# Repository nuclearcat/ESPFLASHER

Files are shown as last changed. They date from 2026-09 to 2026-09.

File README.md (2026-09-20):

# ESPFLASHER
Inexpensive ESP32/ESP8266 programmer

This device implements a USB programmer for ESP32/ESP8266 devices with traditional programming pin management (EN/BOOT0) using [RTS DTR bridge][1].

It also differs from traditional USB-UART converters by a powerful LDO, which allows you to easily power the ESP32 / ESP8266 and related peripherals.
Earlier revisions were manufactured by JLCPCB and tested for programming various devices.

**V3 has not been tested on physical hardware (IRL) yet.** It uses [USB-C with USB 2.0 data](docs/usb-c.md), corrects the header labels and board-edge clearance, uses a ceramic-compatible TI regulator, and retains a single power LED beside the programming header. The RX/TX activity LEDs and their drivers have been removed. It has passed the KiCad checks described in [the revision notes](docs/revision-3.md). Gerbers, BOM and CPL are included.

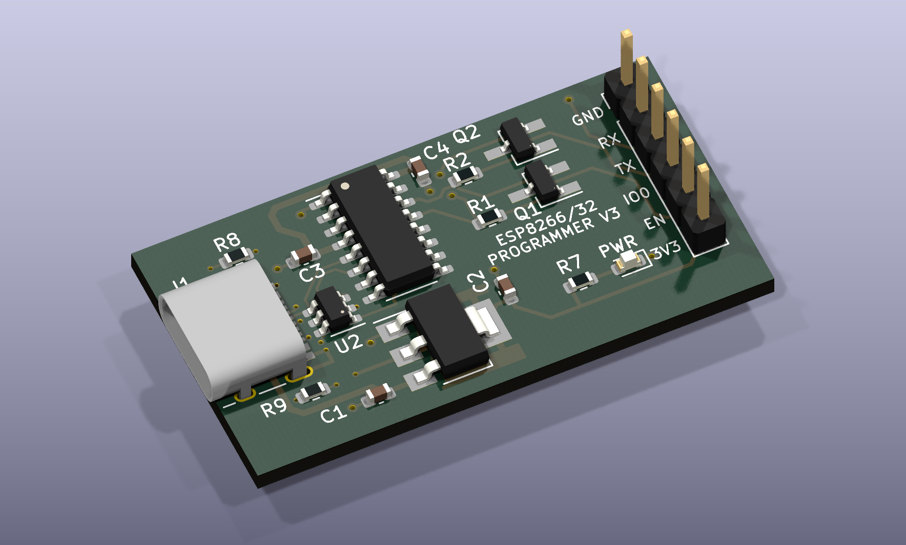
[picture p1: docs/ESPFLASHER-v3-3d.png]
ESPFLASHER V3 3D preview with USB-C connector


[1]: https://raw.githubusercontent.com/nodemcu/nodemcu-devkit/master/Documents/NODEMCU_DEVKIT_SCH.png "Also called Node-MCU auto-program circuit"

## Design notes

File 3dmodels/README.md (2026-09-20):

# USB-C connector model

`HRO_TYPE-C-31-M-12.step` is the HRO TYPE-C-31-M-12 model from
[Keebio-Parts.pretty](https://github.com/keebio/Keebio-Parts.pretty/blob/1486bef23f020c31bf69123c93da199850cc7243/3dmodels/HRO%20%20TYPE-C-31-M-12.step),
copied without modifying its contents. The STEP header credits `ryotagoto`.
The upstream repository's MIT license is included in `LICENSE.keebio`.

J1 references `${KIPRJMOD}/3dmodels/HRO_TYPE-C-31-M-12.step`, so the model
travels with the project and does not require a system library installation.
KiCad model settings:

| Setting | X | Y | Z |
| --- | ---: | ---: | ---: |
| Scale | 1 | 1 | 1 |
| Rotation (degrees) | -90 | 0 | 0 |
| Offset (mm) | -4.47 | -3.65 | 0 |

The rotation and Y/Z offsets follow the upstream assembly footprint, which
uses the same shell mounting-hole coordinates as J1. The X offset centers the
model's 8.94 mm width precisely (upstream uses -4.45 mm). Its shell leg centers
then match the footprint's X = ±4.32 mm mounting slots. The body rests at the
PCB top surface and its opening faces the left board edge. Placement was
checked in KiCad top and oblique renders; the model is for visualization,
with the manufacturer drawing remaining the assembly reference.

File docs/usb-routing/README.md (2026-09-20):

# USB routing comparison

These are historical views of the Micro-USB routing change, before the later
removal of the RX/TX indicators, relocation of the power LED, and USB-C conversion. See the
[current board preview](../ESPFLASHER-v3-3d.png) and [revision notes](../revision-3.md)
for the final V3 layout. The [USB-C conversion](../usb-c.md) supersedes the
connector placement and routing shown here.

These images are generated directly from the KiCad PCB. The before views show
the V2 board immediately before this USB routing change, including the earlier
header-label, regulator and board-edge fixes. Before/after views use identical
camera settings or drawing viewports. Back copper is viewed from the top, so its
features line up with the front layer above it.

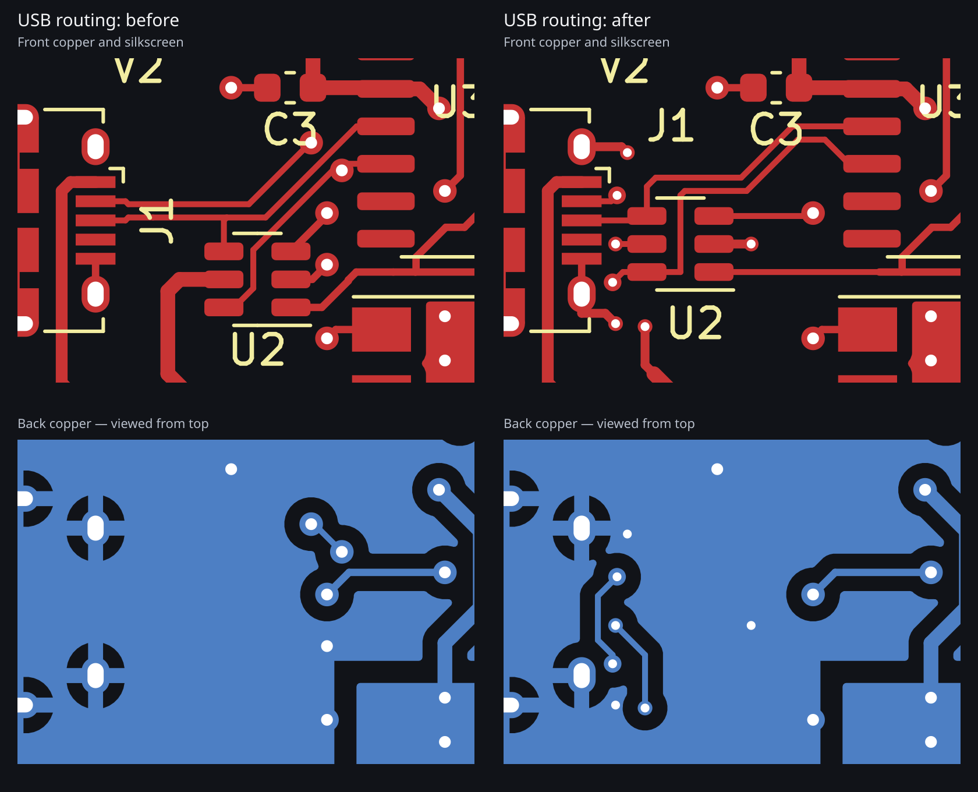
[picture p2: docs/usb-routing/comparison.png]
Before and after USB routing, front and back copper


| View | Before | After |
| --- | --- | --- |
| Full front copper and silkscreen | [Before](before.png) | [After](after.png) |
| Full board 3D render | [Before](before-3d.png) | [After](after-3d.png) |

U2 moves 2.14 mm toward J1 and 1.20 mm upward, with no rotation. Both USB traces
now enter and leave their respective U2 pads rather than connecting protection
through branch traces. The pad assignments and all schematic connections remain
unchanged. The other U2 channels and its supply are rerouted to the new position.

The connector and CH340 have opposite D+/D− pad order. The two-via D− crossover
is now on the connector side of U2, leaving the main protected USB run on the
front layer. That run uses 0.20 mm tracks with 0.25 mm edge-to-edge spacing on
its paired sections, then fans out to the CH340 pads. There are no length-tuning
meanders. Ground vias beside the connector shell connections stitch the layers
near the crossover, and U2 has a short connection to a ground via beside pin 2.

The existing 0.20 mm trace width is retained. This is not a claim of verified
90-ohm differential impedance: that requires a specified fabrication stackup and
an impedance calculation. The back ground fill is continuous under the main
paired route, checked against the filled copper geometry.

KiCad DRC reports no new violations, no unconnected pads and no schematic/PCB
parity issues. The existing J1 footprint-type error and nine footprint-library
warnings remain. Only U2 changes position; all components retain their pin-net
assignments and orientation. Both assembly position files, Gerber archives and
the IPC netlist are updated.

**The current V3 revision remains untested on physical hardware.** USB enumeration, repeated flashing
and ESD performance have not been bench-validated.

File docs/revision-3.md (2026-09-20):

# PCB V3

The earlier Micro-USB board was marked V2. This USB-C revision is V3; its
silkscreen, PCB/schematic revision fields and manufacturing files use revision 3.

This revision addresses review items 1–3, replaces Micro-USB with USB-C,
improves USB routing, and simplifies the LED circuit. The board outline and
header pinout are unchanged. U2 moves to accommodate the larger connector,
and D3/R7 move beside the programming header. The RX/TX indicator branches
are removed. See the [USB-C notes](usb-c.md) for the current connector and
the [USB routing comparison](usb-routing/README.md) for historical Micro-USB views.

## Header labels

Each J2 label is placed at the corresponding pad's Y coordinate, at 2.54 mm pitch.
The power pin is marked `3V3` rather than `VCC`. RX and TX are named from the
programmer's perspective.

| J2 pin | Label | Connection |
| --- | --- | --- |
| 1 (square pad) | GND | Ground |
| 2 | RX | Programmer RX; connect to target TX |
| 3 | TX | Programmer TX; connect to target RX |
| 4 | IO0 | Target boot strap |
| 5 | EN | Target enable/reset |
| 6 | 3V3 | Programmer 3.3 V output |

## Board edge

The project now enforces 0.3 mm copper-to-board-edge clearance. The bottom ground
bridge was moved from Y=60.6 mm to Y=60.4 mm, giving its 0.5 mm tracks 0.35 mm
clearance to the Y=61 mm outline. All zones were refilled with the new rule;
the ground fill is inset approximately 0.3005 mm from the outline.

## Regulator and output capacitor

U1 is **Texas Instruments TLV1117LV33DCYR**, LCSC/JLCPCB **C15578**. Its pinout
matches the existing SOT-223 footprint: pin 1 GND, pin 2 and tab OUT, pin 3 IN.
A project-local symbol records the exact part without relying on an AMS1117
symbol name.

C2 remains the existing 22 µF ceramic capacitor. The
[TI datasheet, section 8.2.2.1](https://www.ti.com/lit/ds/symlink/tlv1117lv.pdf)
specifies ceramic-capacitor stability with zero minimum ESR, recommends at least
1 µF nominal, and requires more than 0.5 µF effective capacitance after bias,
temperature and aging. Preserve that requirement when substituting C2.
Do not substitute an ordinary AMS1117 or TLV1117 for the specified **LV** part.

The replacement is for nominal 5 V USB input: recommended maximum input is 5.5 V
(6 V absolute maximum). This change does not establish a continuous output-current
rating or add reverse-current blocking. Disconnect J2 pin 6 when using an
independently powered target.

## Power indicator

The RX/TX activity LEDs D1/D2, their 2N7002 drivers Q3/Q4, and resistors R3–R6
are removed from the schematic, PCB, BOMs and placement files. Their UART and
supply branch traces are removed as well. The former idle-on LED erratum no
longer applies. Programming and UART connections remain intact.

D3 is the sole remaining LED. It moves to (111.20, 55.62) mm, beside J2's 3V3
label, with a `PWR` silkscreen label. Its 1 kΩ resistor R7 moves to
(107.50, 55.62) mm. Both rotate to 180 degrees; D3's cathode is on the right.
The circuit remains +3V3 → R7 → D3 → GND, so it indicates the presence of the
3.3 V rail rather than UART activity. Existing references are retained for
traceability. The 3.3 V trace to J2 is rerouted below the indicator, and copper
zones are refilled. All other component positions and orientations remain as
they were immediately before this LED change.

## Manufacturing and validation

Both `production/ESPFLASHER.zip` and `jlcpcb/gerber/GERBER-ESPFLASHER.zip` contain
the same regenerated V3 copper, solder mask, paste, silkscreen, outline and drill
files. Both BOMs are regenerated from the current schematic's JLCPCB fields,
including the sourcing updates already present in the schematic before these changes.
The backup archive under `production/backups/` remains historical.

The final USB-C J1 position is (83.18, 50.00) mm at -90 degrees in KiCad,
with U2 at (90.525, 50.80) mm. R8 is at (86.50, 43.50) mm / 0 degrees and
R9 is at (86.50, 56.25) mm / 180 degrees. Both position files include these
changes and the D3/R7 moves; the eight removed indicator components are
omitted. Other existing assembly rotation adjustments are retained. The U1
value in the JLCPCB position file is updated. Confirm J1's mating direction,
pin 1 of U1/U2 and D3's cathode in the assembler's placement preview.

KiCad 9.0.3 validation: no unrouted pads, no schematic/PCB parity issues, no
copper-edge violations, and no ERC electrical errors. After the USB-C change,
DRC reports seven footprint-library warnings and zero errors; ERC reports
27 library warnings and zero errors. The old Micro-USB footprint-type error
is gone. J1's library warning reflects silkscreen lines shortened at the board
edge; its library pad geometry is retained. The other footprint warnings
predate this change.

The USB-C conversion was checked for independent 5.1k CC resistors, both
orientations' D+/D− connections, all VBUS/GND contacts, and unused SBU pins.
Compared with the design just before conversion, R8/R9 are the only added
components, all components other than J1 retain their pad-net assignments,
and only J1/U2 change placement. The schematic PDF and board previews were
inspected. This is design-rule validation, not USB compliance certification.

This revision has not been bench-tested. Check the 3.3 V rail during startup and
load steps, regulator temperature at the intended load, USB enumeration and
repeated flashing with both USB-C plug orientations and with USB-A-to-C and
USB-C-to-C data cables before treating the revised board as hardware-validated.

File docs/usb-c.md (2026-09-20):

# USB-C input

J1 is an HRO **TYPE-C-31-M-12**, LCSC/JLCPCB **C165948**, a compact
16-contact USB-C receptacle for USB 2.0. Its shell is approximately
8.94 × 7.35 mm. It replaces the Micro-USB connector on the existing
40 × 21 mm board outline. The CH340C and the 3.3 V regulator are unchanged.

USB-C describes the connector here: the programmer still uses USB 2.0 data
and nominal 5 V VBUS. There are no SuperSpeed signals, USB PD controller,
or higher-voltage negotiation. Avoid substituting a power-only connector
that omits the USB data contacts.

| J1 contacts | Connection |
| --- | --- |
| A4, A9, B4, B9 | VBUS, feeding the existing regulator input |
| A1, A12, B1, B12, shell S1 | GND |
| A6, B6 | D+, through U2 protection to CH340C |
| A7, B7 | D−, through U2 protection to CH340C |
| A5 / CC1 | R8, 5.1 kΩ to GND |
| B5 / CC2 | R9, 5.1 kΩ to GND |
| A8 / SBU1, B8 / SBU2 | Unconnected |

R8/R9 are separate 0603 1% resistors, UNI-ROYAL **0603WAF5101T5E**,
LCSC/JLCPCB **C23186**. The two Rd terminations allow a USB-C source to
detect the sink in either plug orientation. They do not grant an automatic
1.5 A or 3 A current allowance; this revision adds no source-current
detection and does not change the programmer's unvalidated load rating.

The connector's pin order, locating holes and shell mounting slots were
checked against the [manufacturer's drawing hosted by LCSC](https://www.lcsc.com/datasheet/C165948.pdf).
The component is listed in the [JLCPCB assembly library](https://jlcpcb.com/partdetail/TYPE-C-31-M-12/C165948).
See also [TI's USB-C sink reference circuit, Figure 2](https://www.ti.com/lit/ug/tiduem6/tiduem6.pdf)
for separate CC pull-downs and USB 2.0 contact pairing.

J1 is placed with the board edge at the drawing's recommended insertion
depth. U2 moves inward to clear the larger connector. The two copies of
each USB data signal join near J1; the D− crossover is on the connector
side of U2. Both main data routes pass through their protection pads,
then run together toward the CH340C. Ground copper is refilled, and a
short ground connection joins the connector shell to the adjacent ground
via. The board title moves into the space freed by the removed RX/TX LEDs.

J1 uses a project-local [STEP model](../3dmodels/README.md), with its scale,
rotation and offset configured for this footprint. The updated board preview
includes the connector; its placement was checked in top and oblique KiCad
renders. Use the schematic, PCB footprint and manufacturer drawing for assembly
review.

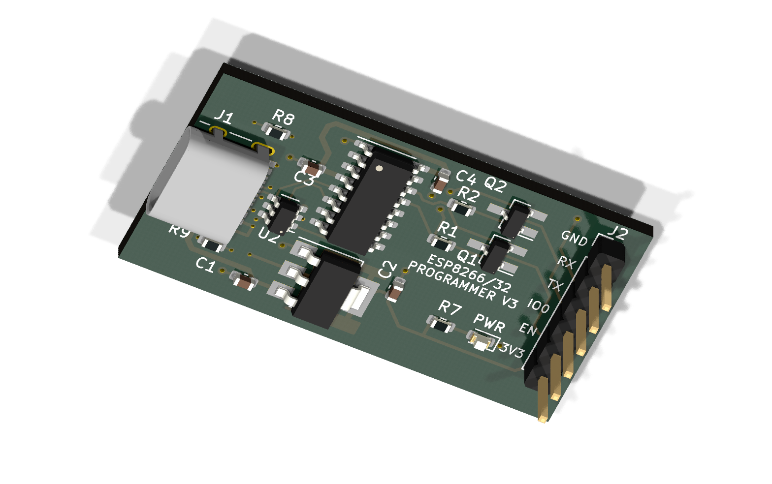
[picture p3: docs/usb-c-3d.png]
USB-C connector in the KiCad 3D view


KiCad reports no DRC electrical/clearance errors, unconnected pads or
schematic/PCB mismatches. ERC has no electrical errors. Library-comparison
warnings are described in the [revision notes](revision-3.md).

Hardware is not yet tested. Verify USB enumeration and repeated flashing
with a data-capable USB-A-to-C cable and USB-C-to-C cable, with the plug
inserted both ways. Also verify supply startup and the intended target load.

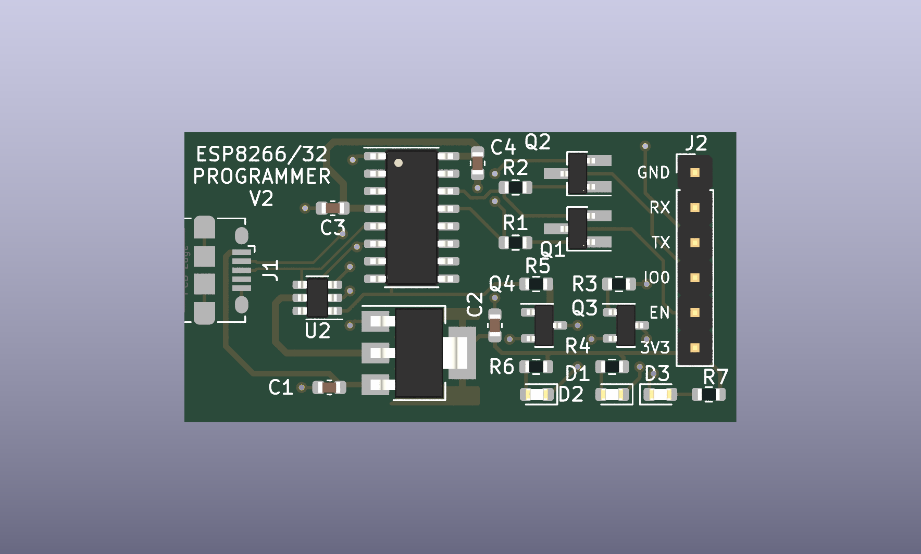
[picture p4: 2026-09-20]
docs/usb-routing/before-3d.png

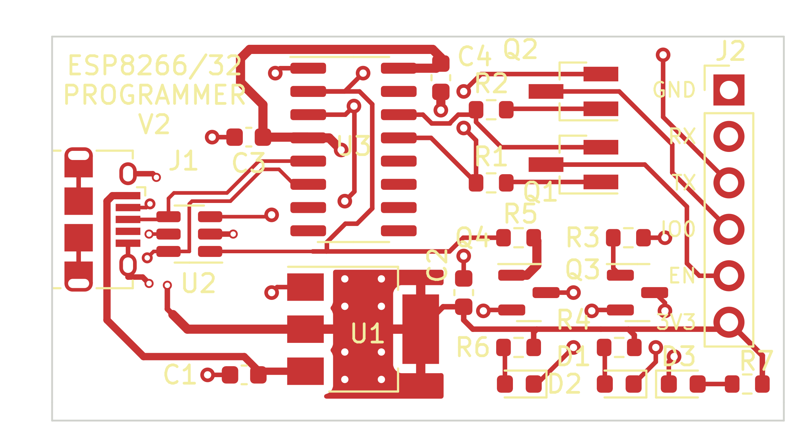
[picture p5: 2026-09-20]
docs/usb-routing/after.png

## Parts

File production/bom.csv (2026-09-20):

Designator | Footprint | Quantity | Value | LCSC Part #
C1, C2 | C_0603_1608Metric | 2 | 22u | C2762594
C3, C4 | C_0603_1608Metric | 2 | 1u | C59302
D3 | LED_0603_1608Metric | 1 | PWR | C2286
J1 | USB_C_Receptacle_HRO_TYPE-C-31-M-12 | 1 | TYPE-C-31-M-12 | C165948
J2 | PinHeader_1x06_P2.54mm_Vertical | 1 | PROG
Q1, Q2 | SOT-23_Handsoldering | 2 | S8050 | C2150
R1, R2 | R_0603_1608Metric | 2 | 10k | C25804
R7 | R_0603_1608Metric | 1 | 1k | C21190
R8, R9 | R_0603_1608Metric | 2 | 5.1k | C23186
U1 | SOT-223-3_TabPin2 | 1 | TLV1117LV33DCYR | C15578
U2 | SOT-23-6 | 1 | SRV05-4 | C558418
U3 | SOIC-16_3.9x9.9mm_P1.27mm | 1 | CH340C | C7464026

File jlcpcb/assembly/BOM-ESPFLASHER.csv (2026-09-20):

Comment | Designator | Footprint | LCSC
22u | C1,C2 | C_0603_1608Metric | C2762594
1u | C3,C4 | C_0603_1608Metric | C59302
PWR | D3 | LED_0603_1608Metric | C2286
TYPE-C-31-M-12 | J1 | USB_C_Receptacle_HRO_TYPE-C-31-M-12 | C165948
PROG | J2 | PinHeader_1x06_P2.54mm_Vertical
S8050 | Q1,Q2 | SOT-23_Handsoldering | C2150
10k | R1,R2 | R_0603_1608Metric | C25804
1k | R7 | R_0603_1608Metric | C21190
5.1k | R8,R9 | R_0603_1608Metric | C23186
TLV1117LV33DCYR | U1 | SOT-223-3_TabPin2 | C15578
SRV05-4 | U2 | SOT-23-6 | C558418
CH340C | U3 | SOIC-16_3.9x9.9mm_P1.27mm | C7464026

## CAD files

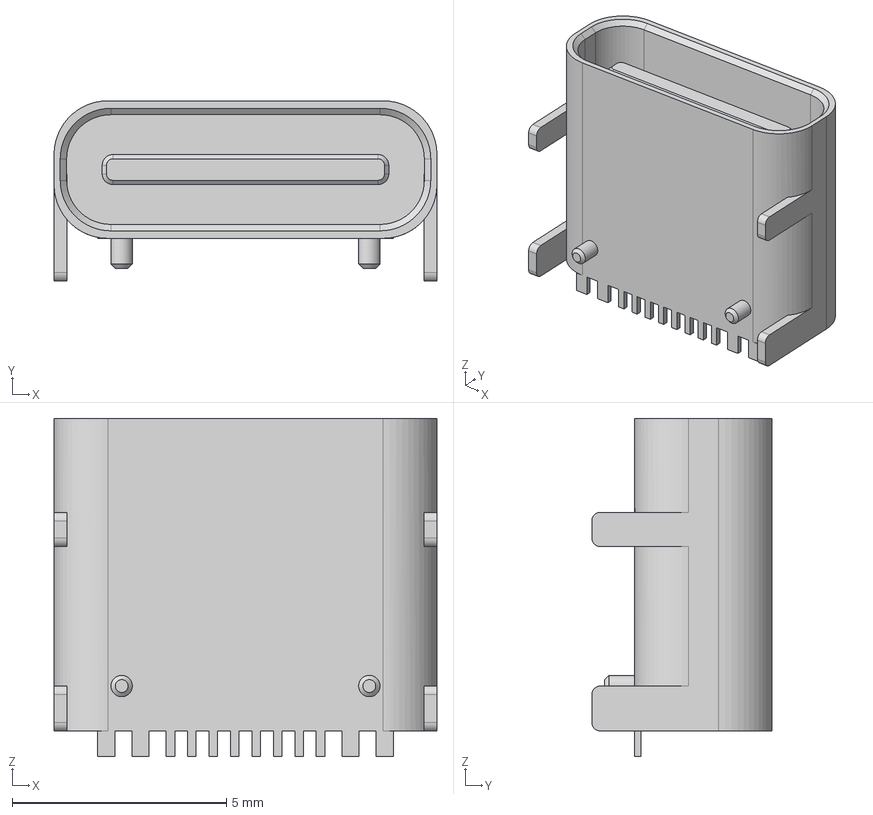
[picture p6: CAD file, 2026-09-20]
3dmodels/HRO_TYPE-C-31-M-12.step
8.94 x 4.21 x 7.90 mm

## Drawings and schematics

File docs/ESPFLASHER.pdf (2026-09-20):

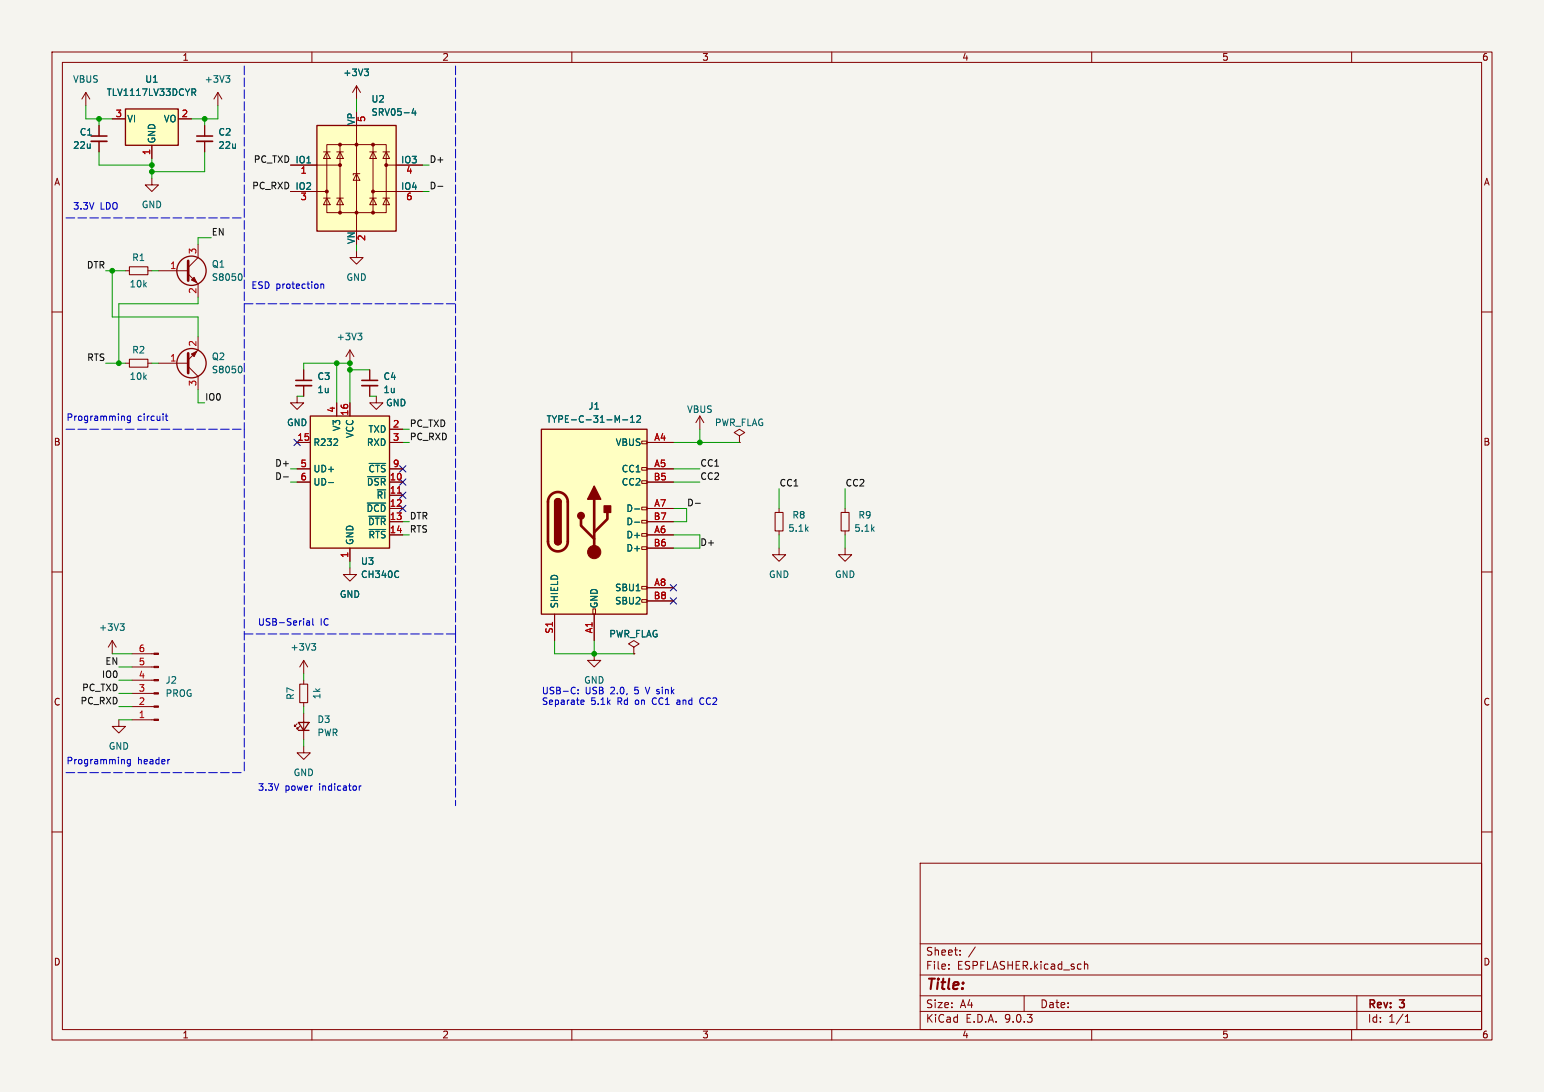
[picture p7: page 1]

1 TXD 2 RXD 3 ~{CTS}9 ~{DSR} 10 ~{RI} 11 ~{DCD} 12 ~{DTR} 13 ~{RTS} 14 GND GND

1 TXD 2 RXD 3 ~{CTS}9 ~{DSR} 10 ~{RI} 11 ~{DCD} 12 ~{DTR} 13 ~{RTS} 14 U3 CH340C GND

Id: 1/1 Title: File: ESPFLASHER.kicad_sch Sheet: /

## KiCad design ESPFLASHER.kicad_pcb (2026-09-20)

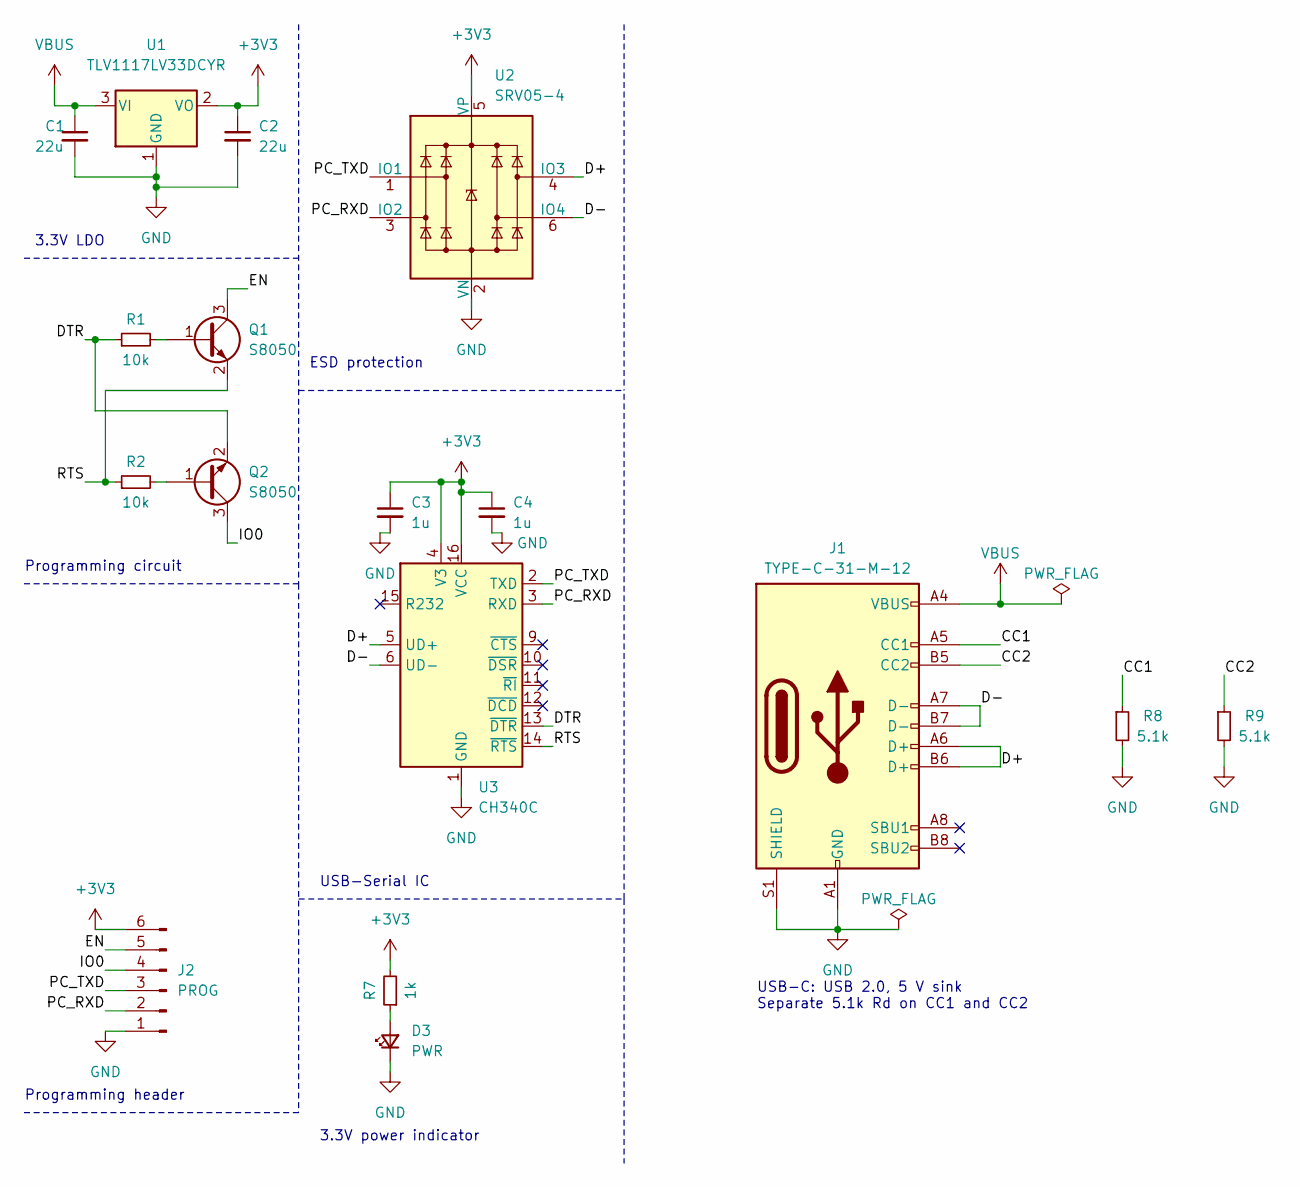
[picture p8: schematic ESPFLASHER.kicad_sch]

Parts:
C1, C2: 22u; C_0603_1608Metric; JLCPCB C2762594
C3, C4: 1u; C_0603_1608Metric; JLCPCB C59302
D3: PWR; LED_0603_1608Metric; JLCPCB C2286
J1: TYPE-C-31-M-12; USB_C_Receptacle_HRO_TYPE-C-31-M-12; JLCPCB C165948
J2: PROG; PinHeader_1x06_P2.54mm_Vertical
Q1, Q2: S8050; SOT-23_Handsoldering; JLCPCB C2150
R1, R2: 10k; R_0603_1608Metric; JLCPCB C25804
R7: 1k; R_0603_1608Metric; JLCPCB C21190
R8, R9: 5.1k; R_0603_1608Metric; JLCPCB C23186
U1: TLV1117LV33DCYR; SOT-223-3_TabPin2; JLCPCB C15578
U2: SRV05-4; SOT-23-6; JLCPCB C558418
U3: CH340C; SOIC-16_3.9x9.9mm_P1.27mm; JLCPCB C7464026

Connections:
+3V3: C2.1, C3.1, C4.1, J2.6, R7.2, U1.2 (VO), U2.5 (VP), U3.4 (V3), U3.16 (VCC)
/CC1: J1.A5 (CC1), R8.1
/CC2: J1.B5 (CC2), R9.1
/D+: J1.A6 (D+), J1.B6 (D+), U2.4 (IO3), U3.5 (UD+)
/D-: J1.A7 (D-), J1.B7 (D-), U2.6 (IO4), U3.6 (UD-)
/DTR: Q2.2 (E), R1.1, U3.13 (~DTR)
/EN: J2.5, Q1.3 (C)
/IO0: J2.4, Q2.3 (C)
/PC_RXD: J2.2, U2.3 (IO2), U3.3 (RXD)
/PC_TXD: J2.3, U2.1 (IO1), U3.2 (TXD)
/RTS: Q1.2 (E), R2.1, U3.14 (~RTS)
GND: C1.2, C2.2, C3.2, C4.2, D3.1 (K), J1.A1 (GND), J1.A12 (GND), J1.B1 (GND), J1.B12 (GND), J1.S1 (SHIELD), J2.1, R8.2, R9.2, U1.1 (GND), U2.2 (VN), U3.1 (GND)
unnamed: D3.2 (A), R7.1
unnamed: Q1.1 (B), R1.2
unnamed: Q2.1 (B), R2.2
VBUS: C1.1, J1.A4 (VBUS), J1.A9 (VBUS), J1.B4 (VBUS), J1.B9 (VBUS), U1.3 (VI)

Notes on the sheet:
ESD protection
Programming circuit
Programming header
3.3V power indicator
USB-Serial IC
3.3V LDO
USB-C: USB 2.0, 5 V sink Separate 5.1k Rd on CC1 and CC2

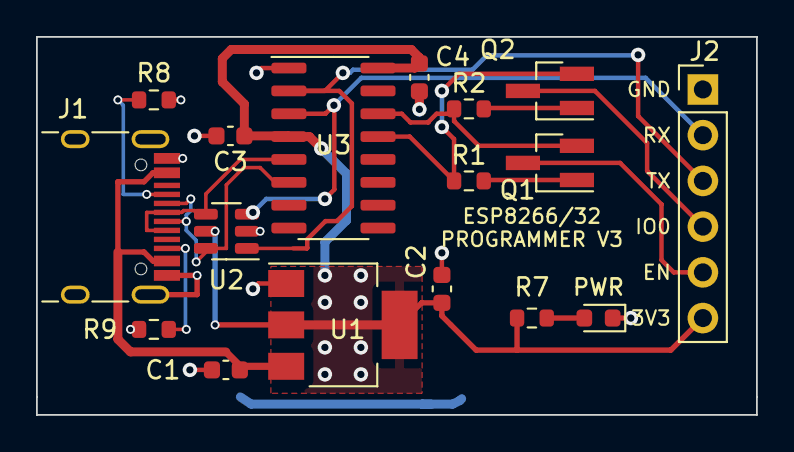
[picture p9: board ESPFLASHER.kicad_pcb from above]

Board: 2 copper layers, 40.0 x 21.0 mm, 17 parts (0 on the bottom side), 16 nets.

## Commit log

2022-10-18 Add PCB/SCH files
    [BOM-ESPFLASHER.csv, ESPFLASHER.kicad_pcb, ESPFLASHER.kicad_sch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]
2024-05-11 Remanufacturing, update to latest KiCAD
    [ESPFLASHER.kicad_pcb, ESPFLASHER.kicad_sch, bom.csv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]
2026-09-20 Update V2 programmer with USB-C and simplified indicators
    Replace the USB connector with a USB-C USB 2.0 receptacle and independent CC pull-downs. Remove RX/TX indicators and move the power LED beside J2. Include regulator, clearance, labeling, and USB routing improvements, with refreshed documentation and manufacturing outputs.
    Validation: ERC and PCB DRC report zero errors; no unconnected pads or schematic parity issues. Library warnings remain documented. Hardware has not been tested.
    [BOM-ESPFLASHER.csv, ESPFLASHER.kicad_pcb, ESPFLASHER.kicad_sch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]
2026-09-20 Mark USB-C board V3 and add connector 3D preview
    [ESPFLASHER.kicad_pcb, ESPFLASHER.kicad_sch, HRO_TYPE-C-31-M-12.step]
2026-09-20 Correct board preview camera tilt
